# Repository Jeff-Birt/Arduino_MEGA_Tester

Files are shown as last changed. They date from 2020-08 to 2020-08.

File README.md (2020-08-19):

# Arduino_MEGA_Tester
This project started out as a way to learn about vintage DRAM chips by building an Arduino based tester. Yes, similar projects exist but part of the fun comes from learning to do it yourself.

After getting the testing of 4164 and 41256 DRAMs working someone asked about testing 4116 DRAMs which require three supply voltages and have the nasty tendency to short the rails together when they fail. This required adding some TVS diode arrays to clamp the I/O to 5V/GND and using some small encapsulated DC-DC converters also made sense.

I started with an Arduino Mega as I had one handy, adn also ported it to the Uno, Micro, and Nano. I designed a PCB around the Micro as well. After using the Mega to build an RCA 1802 tester it ocurred to me that by going back to the Mega with its numerous I/O and larger code space, that I could build a more universal tester.

So, after a 6 month hiatus on the project I picked it up again, moved back to the Mega 2560 and designed a 'Mega Tester' shield for it. The shield accepts 'PODs' which is a daughter board customized for a particular range of ICs. For example the 'DRAM Tester POD' which is for 4116, 4164, 41256 and 41464 DRAMs.

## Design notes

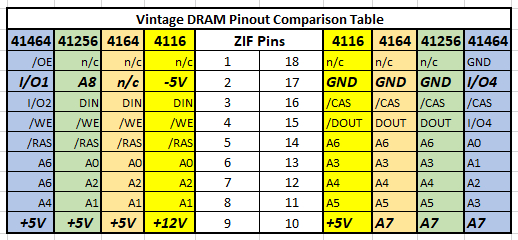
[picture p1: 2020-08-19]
Project Datasheets/DRAMs/DRAM Table/Vintage DRAM Table.PNG

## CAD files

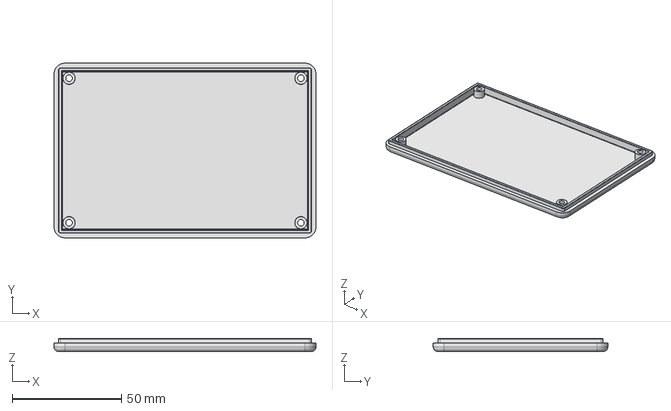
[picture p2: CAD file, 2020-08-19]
Project Datasheets/Enclosure/1591T Lid.stp
120.0 x 80.0 x 5.90 mm

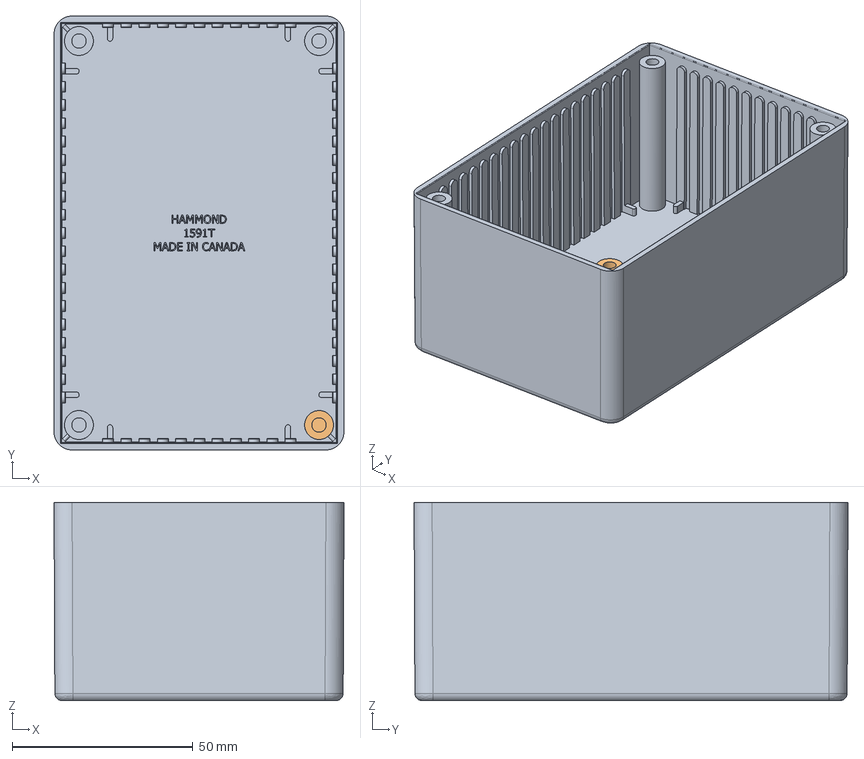
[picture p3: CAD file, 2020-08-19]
Project Datasheets/Enclosure/1591T Box.stp
80.2 x 120.0 x 54.8 mm

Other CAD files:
Project Datasheets/Enclosure/1591TSBK.dwg
Project Datasheets/Enclosure/1591T Box.igs
Project Datasheets/Enclosure/1591T Lid.igs
Project Datasheets/Enclosure/1591TSBK.x_t

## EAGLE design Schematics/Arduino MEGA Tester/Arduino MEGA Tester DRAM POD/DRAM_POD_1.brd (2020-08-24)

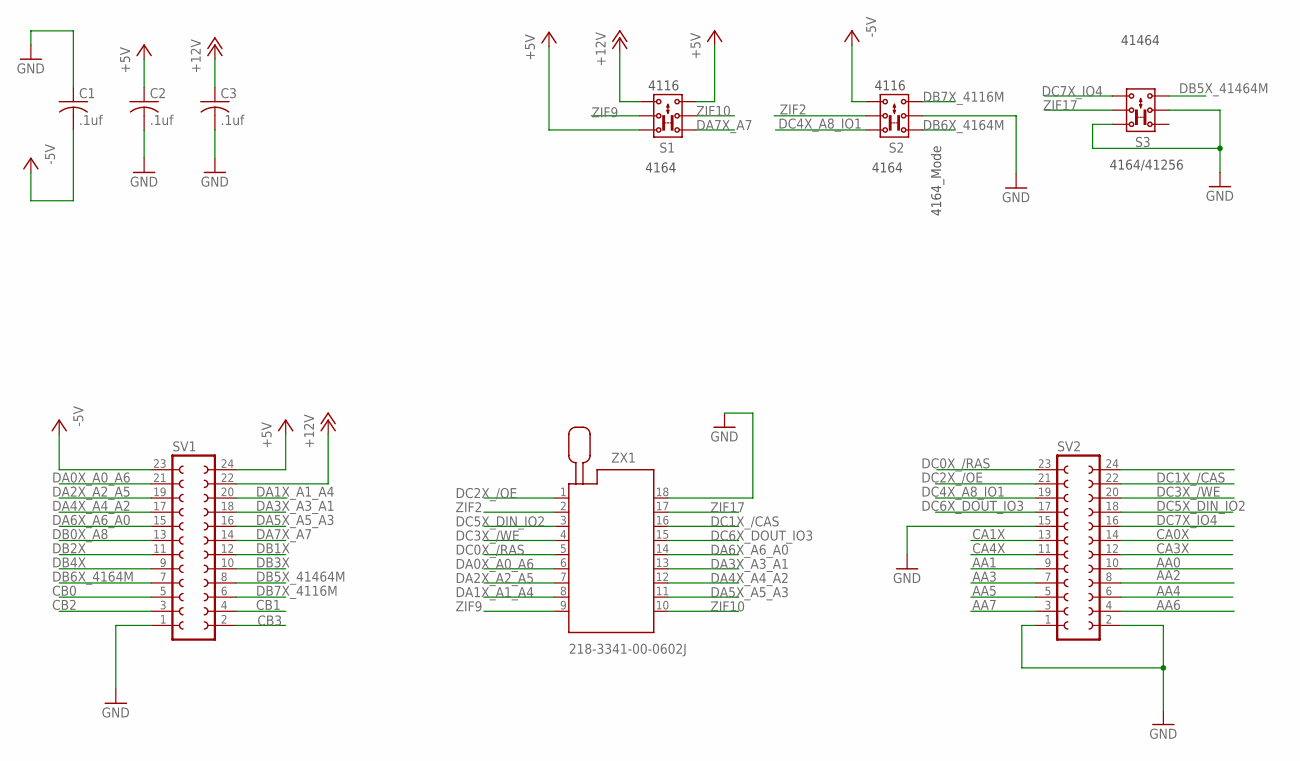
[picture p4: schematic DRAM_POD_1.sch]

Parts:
C1, C2, C3: .1uf; C025-024X044
S1, S2, S3: 2P2T
SV1, SV2: FE12-2
ZX1: 218-3341-00-0602J

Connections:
+5V: C2.1, S1.1.1, S1.3.2, SV1.24
+12V: C3.1, S1.3.1, SV1.22
-5V: C1.2, S2.3.1, SV1.23
AA0: SV2.10
AA1: SV2.9
AA2: SV2.8
AA3: SV2.7
AA4: SV2.6
AA5: SV2.5
AA6: SV2.4
AA7: SV2.3
CA0X: SV2.14
CA1X: SV2.13
CA3X: SV2.12
CA4X: SV2.11
CB0: SV1.5
CB1: SV1.4
CB2: SV1.3
CB3: SV1.2
DA0X_A0_A6: SV1.21, ZX1.6
DA1X_A1_A4: SV1.20, ZX1.8
DA2X_A2_A5: SV1.19, ZX1.7
DA3X_A3_A1: SV1.18, ZX1.13
DA4X_A4_A2: SV1.17, ZX1.12
DA5X_A5_A3: SV1.16, ZX1.11
DA6X_A6_A0: SV1.15, ZX1.14
DA7X_A7: S1.1.2, SV1.14
DB0X_A8: SV1.13
DB1X: SV1.12
DB2X: SV1.11
DB3X: SV1.10
DB4X: SV1.9
DB5X_41464M: S3.3.2, SV1.8
DB6X_4164M: S2.1.2, SV1.7
DB7X_4116M: S2.3.2, SV1.6
DC0X_/RAS: SV2.23, ZX1.5
DC1X_/CAS: SV2.22, ZX1.16
DC2X_/OE: SV2.21, ZX1.1
DC3X_/WE: SV2.20, ZX1.4
DC4X_A8_IO1: S2.1.1, SV2.19
DC5X_DIN_IO2: SV2.18, ZX1.3
DC6X_DOUT_IO3: SV2.17, ZX1.15
DC7X_IO4: S3.3.1, SV2.16
GND: C1.1, C2.2, C3.2, S2.2.2, S3.1.1, S3.2.2, SV1.1, SV2.1, SV2.2, SV2.15, ZX1.18
ZIF2: S2.2.1, ZX1.2
ZIF9: S1.2.1, ZX1.9
ZIF10: S1.2.2, ZX1.10
ZIF17: S3.2.1, ZX1.17

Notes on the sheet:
4164
4116
4164/41256
41464
4164_Mode

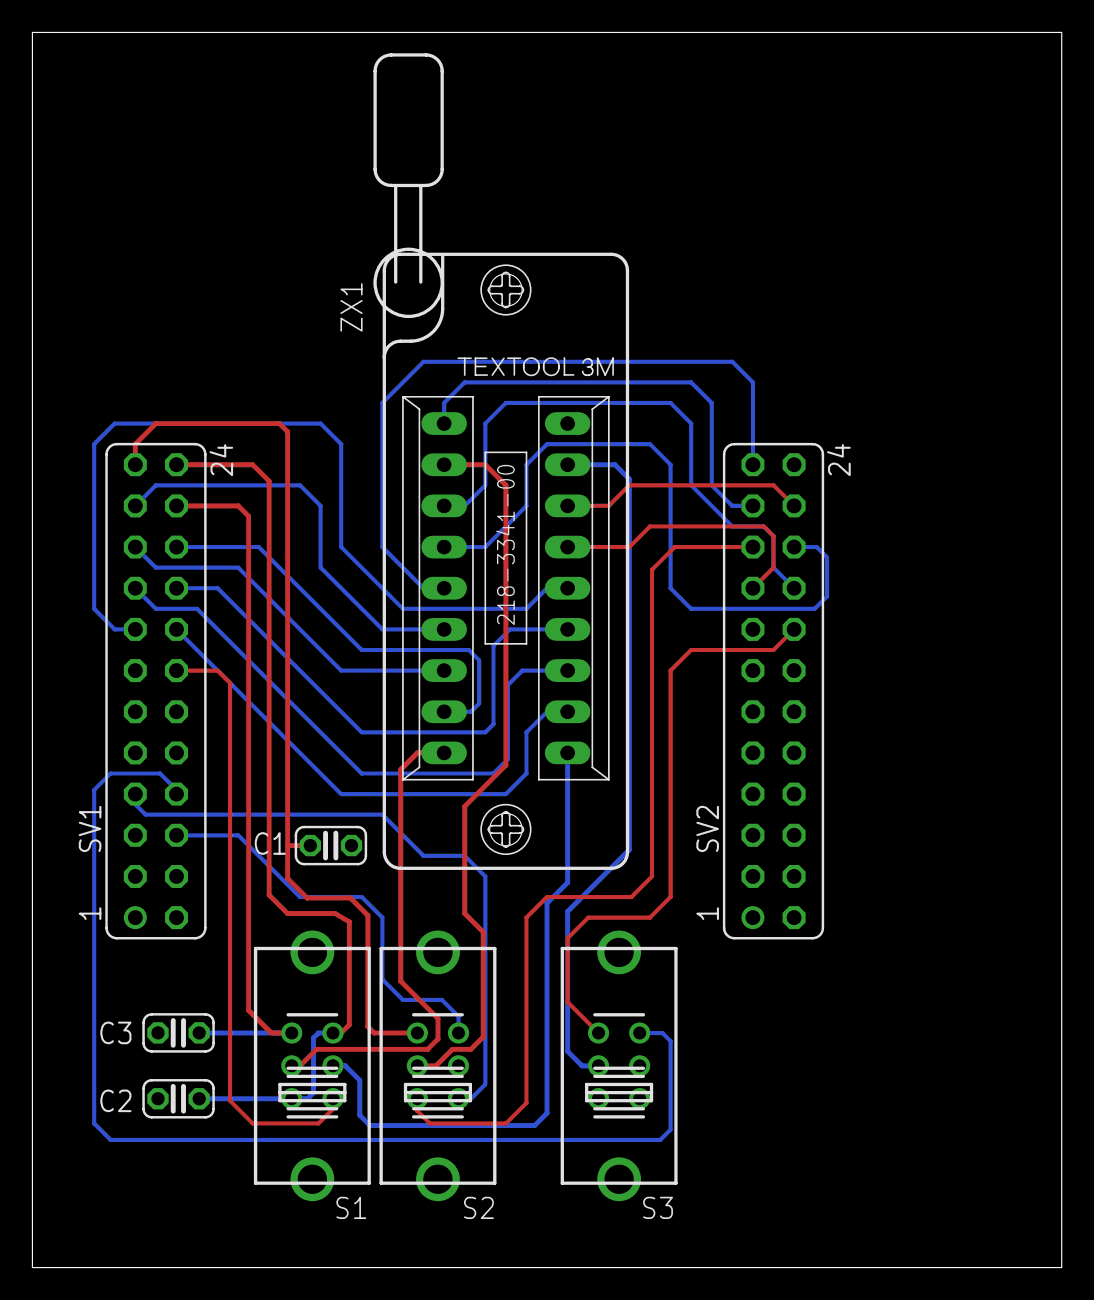
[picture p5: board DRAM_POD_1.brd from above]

Board: 2 copper layers, 63.5 x 76.2 mm, 9 parts (0 on the bottom side), 27 nets.

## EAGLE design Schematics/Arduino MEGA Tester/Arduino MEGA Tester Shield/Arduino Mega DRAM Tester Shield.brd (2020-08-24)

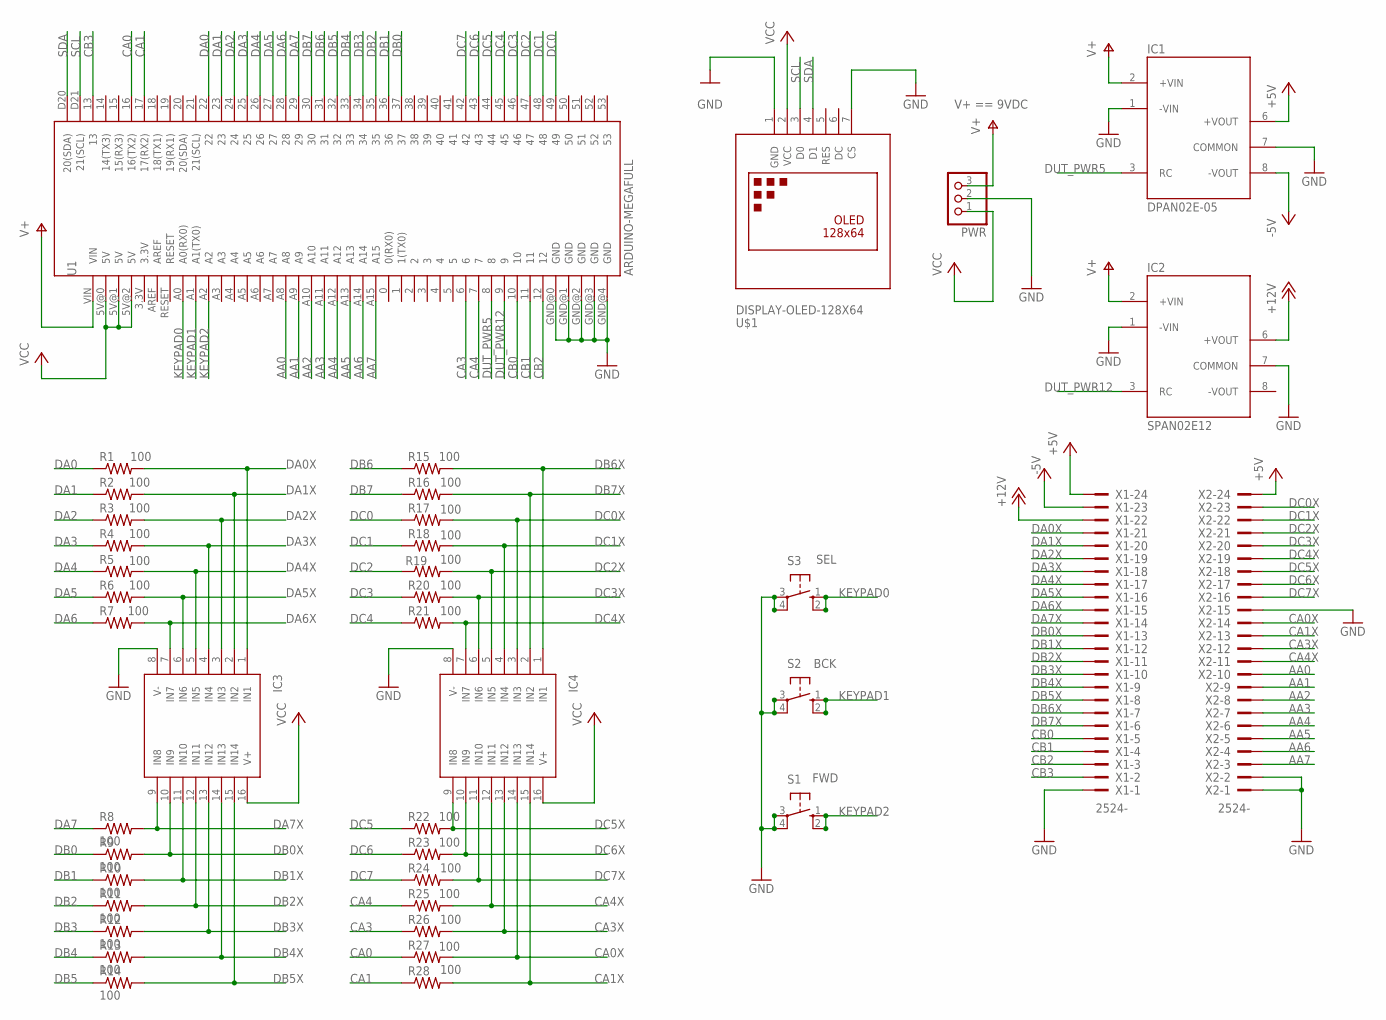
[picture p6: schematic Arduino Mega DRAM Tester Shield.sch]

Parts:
IC1: DPAN02E-05; SIP7
IC2: SPAN02E12; SIP7
IC3, IC4: SP720; DIL16
PWR: PINHD-1X3; 1X03
R1, R2, R3, R4, R5, R6, R7, R8, R9, R10, R11, R12, R13, R14, R15, R16, R17, R18, R19, R20, R21, R22, R23, R24, R25, R26, R27, R28: 100; 0204/7
S1: FWD; B3F-10XX
S2: BCK; B3F-10XX
S3: SEL; B3F-10XX
U1: ARDUINO-MEGAFULL; ARDUINO_MEGA
U$1: DISPLAY-OLED-128X64
X1, X2: 2524-; PAK100/2500-24

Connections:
+5V: IC1.6 (+VOUT), X1.24, X2.24
+12V: IC2.6 (+VOUT), X1.22
-5V: IC1.8 (-VOUT), X1.23
AA0: U1.A8, X2.10
AA1: U1.A9, X2.9
AA2: U1.A10, X2.8
AA3: U1.A11, X2.7
AA4: U1.A12, X2.6
AA5: U1.A13, X2.5
AA6: U1.A14, X2.4
AA7: U1.A15, X2.3
CA0: R27.1, U1.16 (16(TX2))
CA0X: IC4.14 (IN13), R27.2, X2.14
CA1: R28.1, U1.17 (17(RX2))
CA1X: IC4.15 (IN14), R28.2, X2.13
CA3: R26.1, U1.6
CA3X: IC4.13 (IN12), R26.2, X2.12
CA4: R25.1, U1.7
CA4X: IC4.12 (IN11), R25.2, X2.11
CB0: U1.10, X1.5
CB1: U1.11, X1.4
CB2: U1.12, X1.3
CB3: U1.13, X1.2
DA0: R1.1, U1.22
DA0X: IC3.1 (IN1), R1.2, X1.21
DA1: R2.1, U1.23
DA1X: IC3.2 (IN2), R2.2, X1.20
DA2: R3.1, U1.24
DA2X: IC3.3 (IN3), R3.2, X1.19
DA3: R4.1, U1.25
DA3X: IC3.4 (IN4), R4.2, X1.18
DA4: R5.1, U1.26
DA4X: IC3.5 (IN5), R5.2, X1.17
DA5: R6.1, U1.27
DA5X: IC3.6 (IN6), R6.2, X1.16
DA6: R7.1, U1.28
DA6X: IC3.7 (IN7), R7.2, X1.15
DA7: R8.1, U1.29
DA7X: IC3.9 (IN8), R8.2, X1.14
DB0: R9.1, U1.37
DB0X: IC3.10 (IN9), R9.2, X1.13
DB1: R10.1, U1.36
DB1X: IC3.11 (IN10), R10.2, X1.12
DB2: R11.1, U1.35
DB2X: IC3.12 (IN11), R11.2, X1.11
DB3: R12.1, U1.34
DB3X: IC3.13 (IN12), R12.2, X1.10
DB4: R13.1, U1.33
DB4X: IC3.14 (IN13), R13.2, X1.9
DB5: R14.1, U1.32
DB5X: IC3.15 (IN14), R14.2, X1.8
DB6: R15.1, U1.31
DB6X: IC4.1 (IN1), R15.2, X1.7
DB7: R16.1, U1.30
DB7X: IC4.2 (IN2), R16.2, X1.6
DC0: R17.1, U1.49
DC0X: IC4.3 (IN3), R17.2, X2.23
DC1: R18.1, U1.48
DC1X: IC4.4 (IN4), R18.2, X2.22
DC2: R19.1, U1.47
DC2X: IC4.5 (IN5), R19.2, X2.21
DC3: R20.1, U1.46
DC3X: IC4.6 (IN6), R20.2, X2.20
DC4: R21.1, U1.45
DC4X: IC4.7 (IN7), R21.2, X2.19
DC5: R22.1, U1.44
DC5X: IC4.9 (IN8), R22.2, X2.18
DC6: R23.1, U1.43
DC6X: IC4.10 (IN9), R23.2, X2.17
DC7: R24.1, U1.42
DC7X: IC4.11 (IN10), R24.2, X2.16
DUT_PWR5: IC1.3 (RC), U1.8
DUT_PWR12: IC2.3 (RC), U1.9
GND: IC1.1 (-VIN), IC1.7 (COMMON), IC2.1 (-VIN), IC2.7 (COMMON), IC3.8 (V-), IC4.8 (V-), PWR.2, S1.3, S1.4 (P1), S2.3, S2.4 (P1), S3.3, S3.4 (P1), U1.GND@0 (GND), U1.GND@1 (GND), U1.GND@2 (GND), U1.GND@3 (GND), U1.GND@4 (GND), U$1.1 (GND), U$1.7 (CS), X1.1, X2.1, X2.2, X2.15
KEYPAD0: S3.1 (S), S3.2 (S1), U1.A0 (A0(RX0))
KEYPAD1: S2.1 (S), S2.2 (S1), U1.A1 (A1(TX0))
KEYPAD2: S1.1 (S), S1.2 (S1), U1.A2
SCL: U1.D21 (21(SCL)), U$1.3 (D0)
SDA: U1.D20 (20(SDA)), U$1.4 (D1)
V+: IC1.2 (+VIN), IC2.2 (+VIN), PWR.3, U1.VIN
VCC: IC3.16 (V+), IC4.16 (V+), PWR.1, U1.5V@0 (5V), U1.5V@1 (5V), U1.5V@2 (5V), U$1.2 (VCC)

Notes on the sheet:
V+ == 9VDC

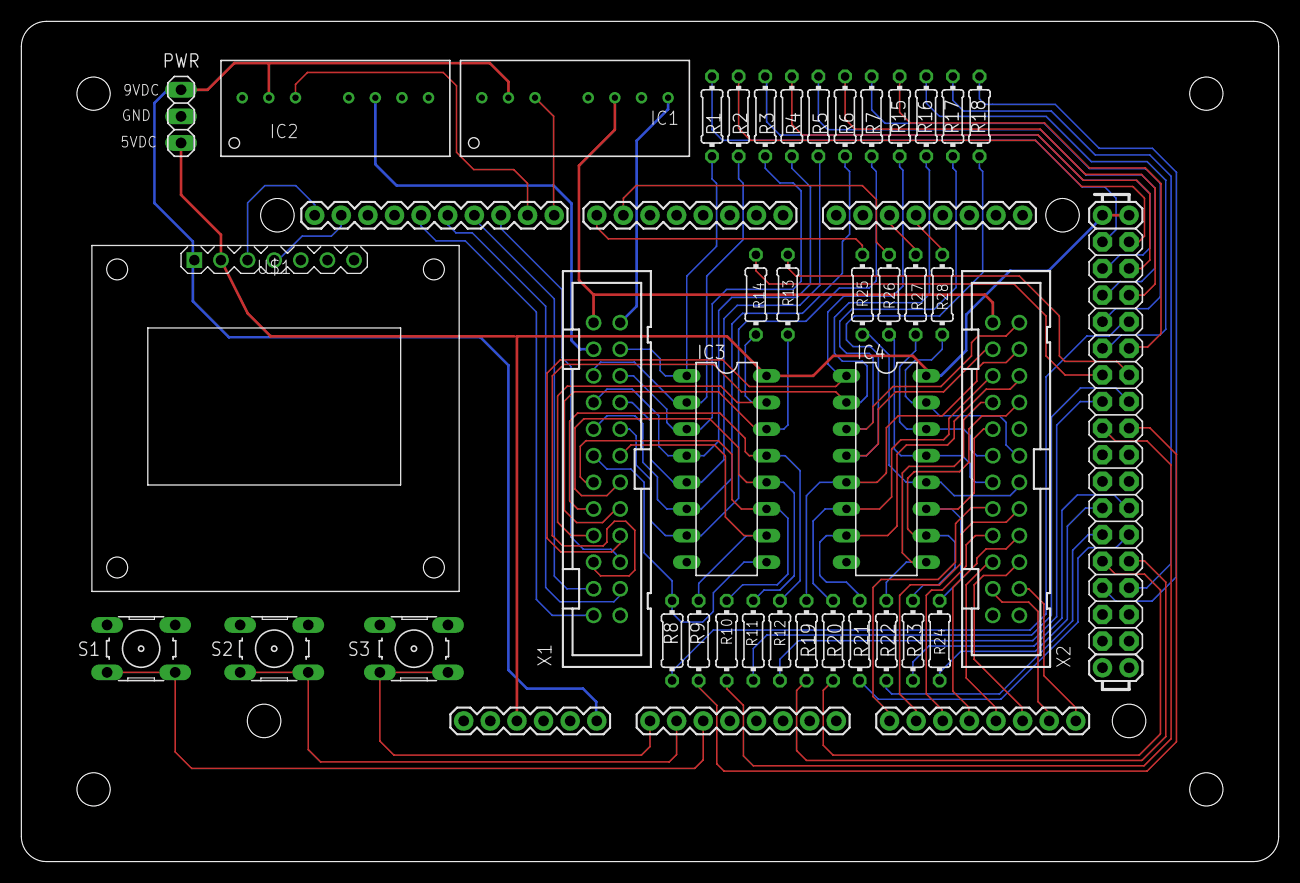
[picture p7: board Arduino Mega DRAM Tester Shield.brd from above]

Board: 2 copper layers, 120.0 x 80.2 mm, 40 parts (0 on the bottom side), 81 nets.

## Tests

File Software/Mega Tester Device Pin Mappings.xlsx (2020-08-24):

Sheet: Port Assignments
 | Definition |  | Arduino
 | Name | Value | Port | Pin
PORTA | DA0 | 0x01 | PA0 | D22
 | DA1 | 0x02 | PA1 | D23
 | DA2 | 0x04 | PA2 | D24
 | DA3 | 0x08 | PA3 | D25
 | DA4 | 0x10 | PA4 | D26
 | DA5 | 0x20 | PA5 | D27
 | DA6 | 0x40 | PA6 | D28
 | DA7 | 0x80 | PA7 | D29
 | Definition |  | Arduino
 | Name | Value | Port | Pin
PORTB | CB0 | 0x01 | PB0 | 53
 | CB1 | 0x02 | PB1 | 52
 | CB2 | 0x04 | PB2 | 51
 | CB3 | 0x08 | PB3 | 50
 | CB4 | 0x10 | PB4 | 10
 | CB5 | 0x20 | PB5 | 11
 | CB6 | 0x40 | PB6 | 12
 |  | 0x80 | PB7 | 13
 | Definition |  | Arduino
 | Name | Value | Port | Pin
PORTC | DB0 | 0x01 | PC0 | 37
 | DB1 | 0x02 | PC1 | 36
 | DB2 | 0x04 | PC2 | 35
 | DB3 | 0x08 | PC3 | 34
 | DB4 | 0x10 | PC4 | 33
 | DB5 | 0x20 | PC5 | 32
 | DB6 | 0x40 | PC6 | 31
 | DB7 | 0x80 | PC7 | 30
 | Definition |  | Arduino
 | Name | Value | Port | Pin
PORTD | SCL | 0x01 | PD0 | 21
 | SDA | 0x02 | PD1 | 20
 | RX1 | 0x04 | PD2 | 19
 | TX1 | 0x08 | PD3 | 18
 |  | 0x10 | PD4
 |  | 0x20 | PD5
 |  | 0x40 | PD6
 |  | 0x80 | PD7
 | Definition |  | Arduino
 | Name | Value | Port | Pin
PORTF | KEYPAD0 | 0x01 | PF0 | A0
 | KEYPAD1 | 0x02 | PF1 | A1
 | KEYPAD2 | 0x04 | PF2 | A2
 |  | 0x08 | PF3 | A3
 |  | 0x10 | PF4 | A4
 |  | 0x20 | PF5 | A5
 |  | 0x40 | PF6 | A6
 |  | 0x80 | PF7 | A7
 | Definition |  | Arduino
 | Name | Value | Port | Pin
PORTH | CA2 | 0x01 | PH0 | 16
 | CA3 | 0x02 | PH1 | 17
 |  | 0x04 | PH2
 |  | 0x08 | PH3
 |  | 0x10 | PH4
 | DUT_PWR5 | 0x20 | PH5 | 8
 | DUR_PWR12 | 0x40 | PH6 | 9
 |  | 0x80 | PH7
 | Definition |  | Arduino
 | Name | Value | Port | Pin
PORTK | AA0 | 0x01 | PK0 | A8
 | AA1 | 0x02 | PK1 | A9
 | AA2 | 0x04 | PK2 | A10
 | AA3 | 0x08 | PK3 | A11
 | AA4 | 0x10 | PK4 | A12
 | AA5 | 0x20 | PK5 | A13
 | AA6 | 0x40 | PK6 | A14
 | AA7 | 0x80 | PK7 | A15
 | Definition |  | Arduino
 | Name | Value | Port | Pin
PORTL | DC0 | 0x01 | PL0 | 49
 | DC1 | 0x02 | PL1 | 48
 | DC2 | 0x04 | PL2 | 47
 | DC3 | 0x08 | PL3 | 46
 | DC4 | 0x10 | PL4 | 45
 | DC5 | 0x20 | PL5 | 44
 | DC6 | 0x40 | PL6 | 43
 | DC7 | 0x80 | PL7 | 42

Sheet: RAM Mappings
Con/Pin | Ard. Pin | POD Name | ZIF Pin | 4116 Pin | 4116 Name | 4164 Pin | 4164 Name | 41256 Pin | 41256 Name | 41464 Pin | 41464 Name
SV1-21 | 22 | DA0X_A0_A6 | 6 | 5 | A0 | 5 | A5 | 5 | A5 | 6 | A6
SV1-20 | 23 | DA1X_A1_A4 | 8 | 7 | A1 | 7 | A1 | 7 | A1 | 8 | A4
SV1-19 | 24 | DA2X_A2_A5 | 7 | 6 | A2 | 6 | A2 | 6 | A2 | 7 | A5
SV1-18 | 25 | DA3X_A3_A1 | 13 | 12 | A3 | 12 | A3 | 12 | A3 | 13 | A1
SV1-17 | 26 | DA4X_A4_A2 | 12 | 11 | A4 | 11 | A4 | 11 | A4 | 12 | A2
SV1-16 | 27 | DA5X_A5_A3 | 11 | 10 | A5 | 10 | A5 | 10 | A5 | 11 | A3
SV1-15 | 28 | DA6X_A6_A0 | 14 | 13 | A6 | 13 | A6 | 13 | A6 | 14 | A0
SV1-14 | 29 | DA7X_A7 | 10s | 9 | +5V | 9 | A7 | 9 | A7 | 10 | A7
SV1-24 |  | +5V | 9s 10s |  |  | 8 | +5V | 8 | +5V
SV1-9 | 32 | DB5X_41464M
SV1-7 | 31 | DB6X_4164M
SV1-6 | 30 | DB7X_4116M
SV2-23 | 49 | DC0X_/RAS | 5 | 4 | /RAS | 4 | /RAS | 4 | /RAS | 5 | /RAS
SV2-22 | 48 | DC1X_/CAS | 16 | 15 | /CAS | 15 | /CAS | 15 | /CAS | 15 | /CAS
SV2-21 | 47 | DC2X_/OE | 1 |  |  |  |  |  |  | 1 | /OE
SV2-20 | 46 | DC3X_/WE | 4 | 3 | /WE | 3 | /WE | 3 | /WE | 4 | /WE
SV2-19 | 45 | DC4X_A8_IO1 | 2s | 1 | -5V | 1 | N/C | 1 | A8 | 2 | IO1
SV2-18 | 44 | DC5X_DIN_IO2 | 3 | 2 | DIN | 2 | DIN | 2 | DIN | 3 | IO2
SV2-17 | 43 | DC6X_DOUT_IO3 | 15 | 14 | DOUT | 14 | DOUT | 14 | DOUT | 15 | IO3
SV2-16 | 42 | DC7X_IO4 | 17s | 16 | GND | 16 | GND | 16 | GND | 17 | IO4

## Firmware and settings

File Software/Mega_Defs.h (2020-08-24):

#pragma once

//PORTA bit           Ard Prt Pin 
#define DA0TODA7  0xFF
//	DA0				      PA0 #22 
//  DA1                   PA1 #23
//  DA2                   PA2 #24
//  DA3                   PA3 #25
//  DA4                   PA4 #26
//  DA5                   PA5 #27
//  DA6                   PA6 #28
//  DA7                   PA7 #29  

//PORTB bit           Ard Prt Pin 
#define CB0T0CB6  0xF7 
//	CB0					  PB0 #53 
//  CB1                   PB1 #52
//  CB2                   PB2 #51
//  CB3                   PB3 #50
//  CB4                   PB4 #10
//  CB5                   PB5 #11
//  CB6                   PB6 #12
//                        PB7 #13  

// PORTC bits         Ard Prt Pin
#define DB0T0DB6  0xFF 
//	DB0					  PC0 #37
//	DB1				      PC1 #36
//	DB2				      PC2 #35
//	DB3				      PC3 #34
//	DB4				      PC4 #33
//	DB5				      PC5 #32  
//  DB6                   PC6 #31
//	DB7			          PC7 #30

// PORTD bits       Ard Prt Pin
#define PRTD      0xFF 
//	SCL					  PD0 #21
//	SDA				      PD1 #20
//	RX1				      PD2 #19
//	TX1				      PD3 #18
//					      PD4
//					      PD5  
//                        PD6
//				          PD7

// PORTF bits       Ard Prt Pin
#define PRTF      0xFF 
//	KEYPAD0				  PF0 #A0
//	KEYPAD1				  PF1 #A1
//	KEYPAD2				  PF2 #A2
//	    				  PF3 #A3
//					      PF4 #A4
//					      PF5 #A5
//                        PF6 #A6
//				          PF7 #A7

// PORTH bits       Ard Prt Pin
#define PRTH      0xFF 
//	CA2					  PH0 16
//	CA3				      PH1 17
//					      PH2 
//	     				  PH3 
//					      PH4
//	DUT_PWR5		      PH5 8
//  DUT_PWR12             PH6 9
//				          PH7

// PORTK bits         Ard Prt Pin
#define PRTK      0xFF 
//	AA0					  PK0 #A8
//	AA1				      PK1 #A9
//	AA2				      PK2 #A10
//	AA3    				  PK3 #A11
//	AA4				      PK4 #A12
//	AA5     		      PK5 #A13
//  AA6                   PK6 #A14
//	AA7 		          PK7 #A15

// PORTL bits         Ard Prt Pin
#define PRTL      0xFF 
//	DC0					  PK0 #49
//	DC1				      PK1 #48
//	DC2				      PK2 #47
//	DC3    				  PK3 #46
//	DC4				      PK4 #45
//	DC5     		      PK5 #44
//  DC6                   PK6 #43
//	DC7 		          PK7 #42

//PORTL bit         Ard Prt Pin  DRAM
#define DOUT    0x01 // PL0 #49  #14
 
// to set pins to HIZ set DDRx bits to zero and set corresponding PORTx pin low
void initTest()
{
  DDRA = DDRA | A0TOA7;
  DDRC = DDRC | A8;
  DDRC = DDRC | DIN | RAS | CAS | WE | GRN_LED | DUT_PWR | BLU_LED; // outputs
  DDRL = DDRL & ~DOUT; // input

  PORTC = PORTC | RAS | CAS | WE;  // set HIGH
  PORTC = PORTC & ~(GRN_LED | BLU_LED); // turn off LEDs
  PORTC = PORTC & ~DUT_PWR; // turn ON +5V to DUT
}

// For HIZ set DDRx bits to zero and set corresponding PORTx pins low
void initStandby()
{
  DDRA = DDRA & ~A0TOA7;
  DDRC = DDRC & ~A8;
  DDRC = DDRC & ~(DIN | RAS | CAS | WE);
  DDRL = DDRL & ~DOUT;

  PORTA = PORTA & ~A0TOA7;
  PORTC = PORTC & ~A8;
  PORTC = PORTC | DUT_PWR; // turn OFF +5V to DUT
  PORTC = PORTC & ~(DIN | RAS | CAS | WE);
  PORTL = PORTL & ~DOUT;
}

inline void setDIN(byte pattern, byte bitMask)
{
  PORTC = (PORTC & ~DIN) | ( ((pattern & bitMask)>0) ? DIN : 0); // clear DIN bit, conditinally set
}

inline void setCol(int col)
{
  PORTA = (byte)col;    // Write out COL address
  PORTC = (PORTC & ~A8) | (col >> 8); // not using rest of PORTC only bit0 
}

inline void setRow(int row)
{
  PORTA = (byte)row;    // 
  PORTC = (PORTC & ~A8) | (row >> 8); // not using rest of PORTC only bit0
}

inline void resetCAS()
{
  PORTC = PORTC | CAS;  // Set CAS HIGH
}

inline void setCAS()
{
  PORTC = PORTC & ~CAS; // Set CAS LOW
}

inline void setRAS()
{
  PORTC = PORTC & ~RAS; // set RAS low
}

inline void resetRAS()
{
  PORTC = PORTC | RAS;  // Set RAS HIGH
}

inline void setWE()
{
  PORTC = PORTC & ~WE;  // Set WE low for write
}

inline void resetWE()
{
  PORTC = PORTC | WE;   // Set WE high to complete write
}

inline bool readBit()
{
  return ((PINL & DOUT) != 0);
}

inline void refreshRow(int row)
{
    PORTA = (byte)row;      // & 0xFF implicit
    PORTC = (PORTC & ~A8) | (row >> 8); // not using rest of PORTC only bit0
    PORTC = PORTC & ~RAS; // set RAS low
    PORTC = PORTC | RAS;  // set RAS high
}

inline void ledOFF()
{
  PORTC = PORTC & ~GRN_LED; // turn off grn LED
}

inline void ledON()
{
  PORTC = PORTC | GRN_LED; // turn off grn LED
}

inline void ledToggle()
{
  PORTC = PORTC ^ GRN_LED; // toggle grn LED
}

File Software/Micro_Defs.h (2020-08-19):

#pragma once

//PORTB bit         Ard Prt Pin  DRAM
//  RXLED               PB0 
#define A0TOA6  0xFF // PB1 #17  #05
//                      PB2 #18  #07
//                      PB3 #16  #06
//                      PB4 #30  #12
//                      PB5 #31  #11
//                      PB6 #32  #10
//                      PB7 #33  #13

//PORTC bit         Ard Prt Pin  DRAM
//                      PC0
//                      PC1
//                      PC2
//                      PC3
//                      PC4
//                      PC5
#define GRN_LED 0x40 // PC6 #27
//                      PC7 

//PORTD bit         Ard Prt Pin  DRAM
// SDA                  PD0
// SCL                  PD1
//                      PD2
//                      PD3
#define KEYPAD  0x10 // PD4 #26
//                      PD5
#define A7TOA8  0xC0 // PC6 #34  #01
//                      PC7 #28  #09

//PORTF bits        Ard Prt Pin  DRAM
#define CAS     0x01 // PF0 #09  #15
#define RAS     0x02 // PF1 #08  #04
//              0x04    PF2
//              0x08    PF3
#define WE      0x10 // PF4 #07  #03
#define DIN     0x20 // PF5 #06  #02
#define DOUT    0x40 // P65 #05  #14 
#define DUT_PWR 0x80 // PF7 #04


// to set pins to HIZ set DDRx bits to zero and set corresponding PORTx pin low
void initTest()
{
  DDRB = DDRB | A0TOA6;
  DDRD = DDRD | A7TOA8;
  DDRC = DDRC | GRN_LED;
  DDRF = DDRF | CAS | RAS | WE | DIN | DUT_PWR; // outputs
  DDRF = DDRF & ~DOUT; // input

  PORTC = PORTC & ~GRN_LED; // turn off LEDs
  PORTF = PORTF | RAS | CAS | WE;  // set HIGH
  PORTF = PORTF & ~DUT_PWR; // turn ON +5V to DUT 
}

// For HIZ set DDRx bits to zero and set corresponding PORTx pins low
void initStandby()
{
  DDRB = DDRB & ~A0TOA6;
  DDRD = DDRD & ~A7TOA8;
  DDRC = DDRC | GRN_LED;
  DDRF = DDRF & ~(DIN | RAS | CAS | WE | DOUT);
  //DDRF = DDRF & ~DOUT;
  //DDRF = DDRF & ~(DIN | RAS | CAS | WE);
  //DDRF = DDRF & ~DOUT;

  PORTB = PORTB & ~A0TOA6;
  PORTD = PORTD & ~A7TOA8;
  PORTF = PORTF | DUT_PWR; // turn OFF +5V to DUT
  PORTF = PORTF & ~(DIN | RAS | CAS | WE | DOUT);
  //PORTF = PORTF & ~DOUT;
  //PORTF = PORTF & ~(DIN | RAS | CAS | WE);
  //PORTF = PORTF & ~DOUT;
}

// set Data IN pin of DRAM
//inline void setDIN(byte pattern, byte bitMask)
inline void setDIN(bool state)
{
  //PORTF = (PORTF & ~DIN) | ( ((pattern & bitMask)>0) ? DIN : 0); // clear DIN bit, conditinally set
  PORTF = (PORTF & ~DIN) | (state ? DIN : 0); // clear DIN bit, conditinally set
}

// set column address, could combine with row as well
inline void setCol(int col)
{
  PORTB = (byte)(col << 1);   // Write out COL address
  PORTD = (PORTD & ~A7TOA8) | ((col & 0x180) >> 1); //
}

inline void setRow(int row)
{
  PORTB = (byte)(row << 1);    // Write out ROW address
  PORTD = (PORTD & ~A7TOA8) | ((row & 0x180) >> 1); // 
}

// set Column Address Select HIGH (off)
inline void resetCAS()
{
  PORTF = PORTF | CAS;  // Set CAS HIGH
}

// set Column Address Select LOW (on)
inline void setCAS()
{
  PORTF = PORTF & ~CAS; // Set CAS LOW
}

// set Row Address Select HIGH (off)
inline void resetRAS()
{
  PORTF = PORTF | RAS;  // Set RAS HIGH
}

// set Row Address Select LOW (on)
inline void setRAS()
{
  PORTF = PORTF & ~RAS; // set RAS low
}

// set Write Enable HIGH (off)
inline void resetWE()
{
	PORTF = PORTF | WE;   // Set WE high to complete write
}

// set Write Enable LOW (on)
inline void setWE()
{
  PORTF = PORTF & ~WE;  // Set WE low for write
}

// read bit state from DRAM DOUT pin
inline bool readDOUT()
{
  return ((PINF & DOUT) != 0);
}

// refresh row to maintain DRAM data
inline void refreshRow(int row)
{
  PORTB = (byte)(row << 1);    // Write out ROW address
  PORTD = (PORTD & ~A7TOA8) | ((row & 0x180) >> 1); // 
  PORTF = PORTF & ~RAS; // set RAS low
  PORTF = PORTF | RAS;  // set RAS high
}

// turn LED off
inline void ledOFF()
{
  PORTC = PORTC & ~GRN_LED; // turn off grn LED
}

// turn LED on
inline void ledON()
{
  PORTC = PORTC | GRN_LED; // turn off grn LED
}

// toggle LED state
inline void ledToggle()
{
  PORTC = PORTC ^ GRN_LED; // toggle grn LED
}

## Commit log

2020-08-19 Initial commit of Arduino MEGA Tester
    [1591T Box.igs, 1591T Box.stp, 1591T Lid.igs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]
2020-08-24 Moved a few I/O around. Added some pin mapping files. Adjusted OLED position.
    [Arduino Mega DRAM Tester Shield.brd, Arduino Mega DRAM Tester Shield.sch, DRAM_POD_1.brd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]

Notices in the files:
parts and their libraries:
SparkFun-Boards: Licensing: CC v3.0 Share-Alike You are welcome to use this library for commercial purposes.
